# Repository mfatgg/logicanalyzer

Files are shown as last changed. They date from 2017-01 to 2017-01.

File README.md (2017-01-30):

# logicanalyzer

Hardware features:
- This is a DIY hobby project to build a simple logic analyzer.
- Firmware is done in C for an Atmel AVR Atmega32 controller.
- Cheap cache sram circuits from old 386 mainboards are used for fast sample snapshot storage.
- Prototype was build from scratch using wire wrap board with through-hole components.

Firmware features:
- Samplerate can be selected by user (divided from external crystal oscillator or manually switched).
- Pre-trigger and post-trigger length can be selected.
- Simple trigger conditions can be used.
- UART transport protection by CRC-16

Control software features:
- Serial communication library
- Set trigger and samplerate
- Get full snapshot ram content
- Verify correct serial transport by CRC-16
- Store logic analyter data in .VCD file for later viewing by e.g. GTKwave

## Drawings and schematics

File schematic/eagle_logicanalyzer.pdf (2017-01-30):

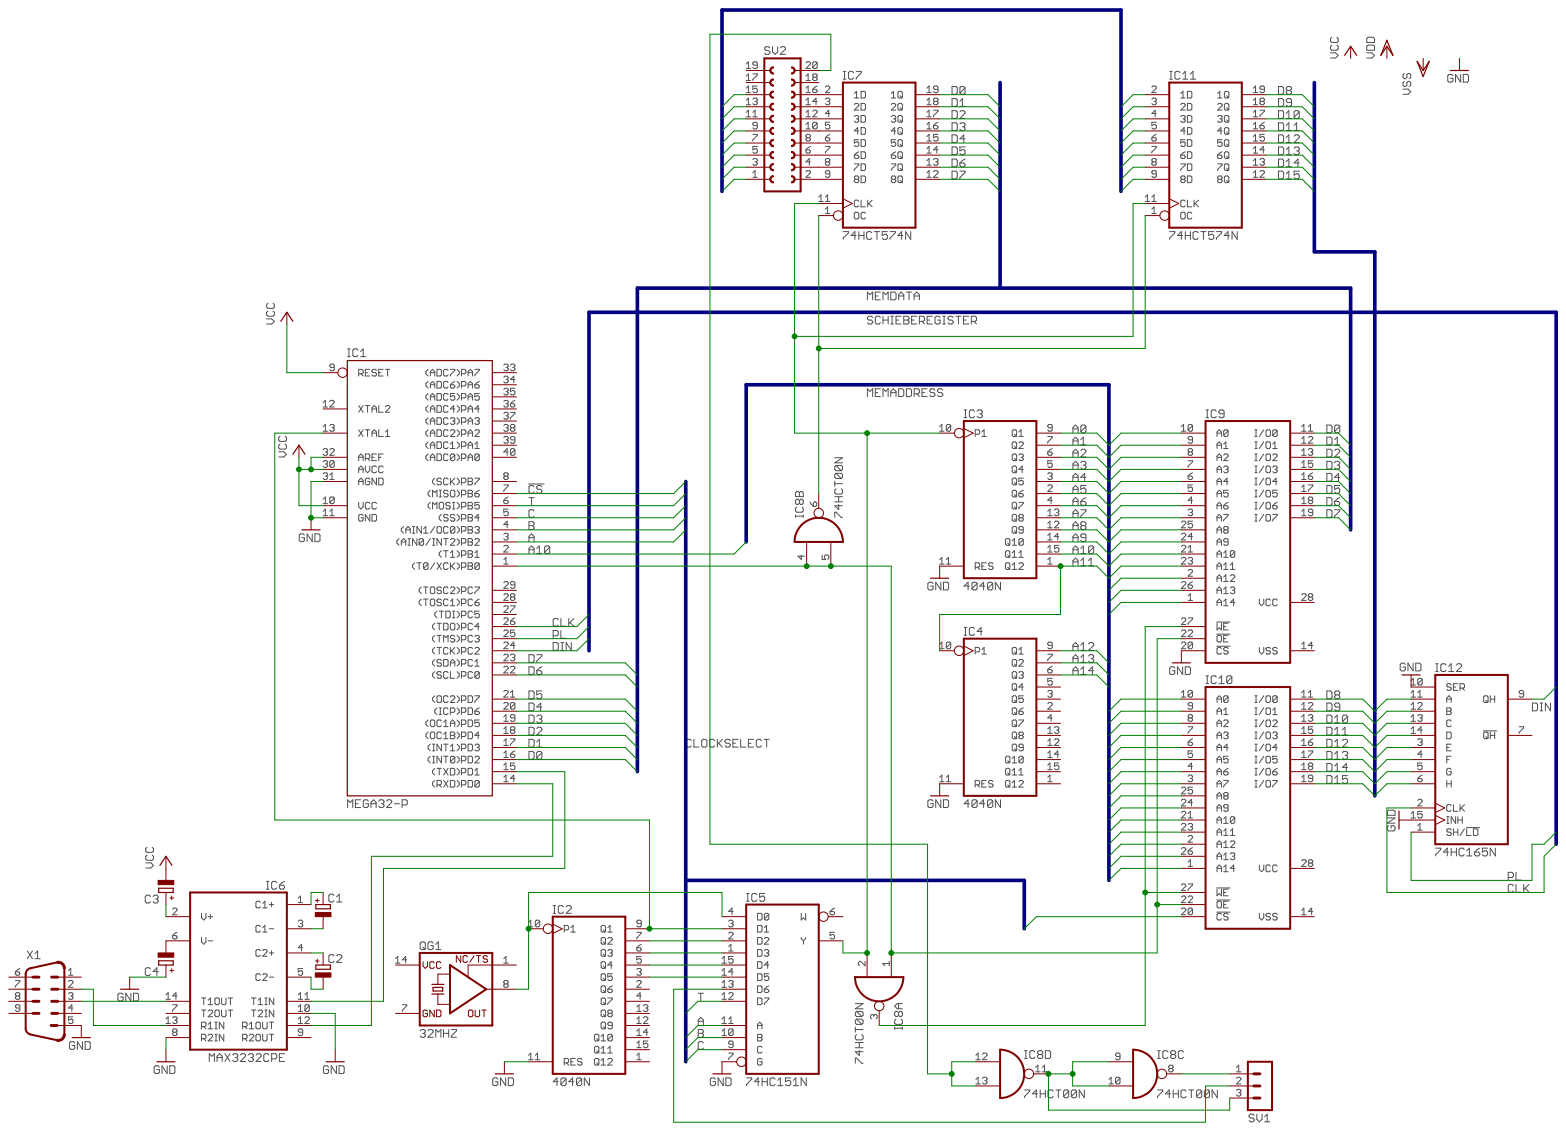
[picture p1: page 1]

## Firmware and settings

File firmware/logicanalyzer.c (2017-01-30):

#ifndef F_CPU
#warning "F_CPU was not defined before, will do now with 16000000"
#define F_CPU 16000000L    // system clock in Hz, "L" at the end is important, DO NOT use "UL"!
#endif

// Select soft uart for arbitrary avr pin usage
// (hardware uart is only available at dedicated pin locations)
#define USE_SOFTUART

//#define BAUD 500000L
//#define BAUD 460800L
//#define BAUD 230400L
#define BAUD 115200L
//#define BAUD 57600L
//#define BAUD 38400L
//#define BAUD 19200L

// Select size of sram circuit used [in bytes]
#define SRAMSIZE 32768L

// System includes
#include <avr/io.h>
#include <util/delay.h>
#include <avr/interrupt.h>

// User includes
#include "crc16.h"


#ifdef USE_SOFTUART

    /* Define external uart functions
     * (external source is assembly for critical uart timing to match baudrate)
    */
    #include "uart.h"
    // Obsolete hardware init for soft uart
    #define init_uart() ;

#else

    // Calculations
    #define UBRR_VAL ((F_CPU+BAUD*8)/(BAUD*16)-1)       // round cleverly
    #define BAUD_REAL (F_CPU/(16*(UBRR_VAL+1)))         // real baudrate
    #define BAUD_ERROR ((BAUD_REAL*1000)/BAUD-1000)     // error per mill

    // Verify selected baudrate can be used with minimal error for the given CPU clock.
    #if ((BAUD_ERROR>10) || (BAUD_ERROR<-10))
    #error Systematic baudrate error is too high! (> 1%)
    #endif

    /*
     * initialize the avr
     */
    void init_uart(void){
        UCSRB |= (1<<RXEN)|(1<<TXEN);                   // enable uart rx+tx
        UCSRC |= (1<<URSEL)|(1<<UCSZ1)|(1<<UCSZ0);      // async 8N1

        UBRRH = UBRR_VAL >> 8;
        UBRRL = UBRR_VAL & 0xFF;
    }

    // status register of newer AVRs have different names, here for ATmega16:
    void uart_putc(unsigned char c)
    {
        while (!(UCSRA & (1 << UDRE)));     // wait until sending is possible
        UDR = c;                            // send character
    }

    /*
     * receive a char over UART
     */
    uint8_t uart_getc( void )
    {
        /* Wait for data to be received */
        while (!(UCSRA & (1 << RXC)));
        /* Get and return received data from buffer */
        return UDR;
    }

#endif


/*
 * start counting write cycles:
 * enable extern T1 pin, falling edge
 */
#define starttimer() TCCR1B = ((1 << WGM12) | (3 << CS11))

/*
 * stop counting write cycles
 */
#define stoptimer() TCCR1B = (1 << WGM12)

/* switch SRAM to WRITE mode */
#define sramwritemode() PORTB |= 1

/* switch SRAM to READ mode */
#define sramreadmode() PORTB &= ~1

/* set SRAM clock line (T) to HIGH */
#define clkhigh() PORTB |= (1 << 5)

/* set SRAM clock line (T) to LOW */
#define clklow() PORTB &= ~(1 << 5)

/* write 1 byte (8 bit) to external SRAM */
#define sramwrite (data) \
    PORTD = (PORTD & ~(0xFC)) | ((data & 0x3F) << 2); \
    PORTC = (PORTC & ~(0x03)) | ((data & 0xC0) >> 6);

/* read 1 byte (8 bit) from external SRAM */
#define sramread() ((PIND & 0xFC) >> 2) | ((PINC & 0x03) << 6)

/*
 * select samplerate for next snapshot:
 *
 * 0 -> 32.00Mhz  (24.00 Mhz)
 * 1 -> 16.00Mhz  (12.00 Mhz)
 * 2 ->  8.00Mhz  ( 6.00 Mhz)
 * 3 ->  4.00MHz  ( 3.00 Mhz)
 * 4 ->  2.00MHz  ( 1.50 Mhz)
 * 5 ->  1.00MHz  ( 0.75 Mhz)
 * 6 -> external
 * 7 -> avr (internal)
 */
#define setsamplerate(srate) PORTB = (PORTB & ~(0x07 << 2)) | ((srate & 0x07) << 2)



// recording state (1 = on, 0 = off),
// volatile because it's used in interrupt routine
volatile uint8_t recording = 0;



void dataoutmode(void)
{
    /* PORT D:
        Bit0: UART-RX, Bit1: UART-TX, Bit2-7: D0-D5 */
    DDRD = 0xFE;
    PORTD = 0xFD;
    /* PORT C:
        Bit0-1: D6-D7 */
    DDRC = 0xFF;
    PORTC = 0xFF;
}


void datainmode(void)
{
    /* PORT D:
        Bit0: UART-RX, Bit1: UART-TX, Bit2-7: D0-D5 */
    DDRD = 0x02;
    PORTD = 0xFD;
    /* PORT C:
        Bit0-1: D6-D7 */
    DDRC = 0xFC;
    PORTC = 0xFF;
}


void init (void)
{
    DDRA = 0xFF;
    PORTA = 0xFF;
    DDRB = 0xFD;
    PORTB = 0x3C;
}


/*
 * set the counter
 */
void init_count(void){
    TCCR1A = 0;
    TCCR1B = (1 << WGM12);
    TCNT1 = 0;
    OCR1A = 15;     // count 15 falling edges of A10 line (=32k memory, 17k pretrigger?)
    TIMSK |= (1 << OCIE1A);
}


/*
 * Long variable delay time, unit in ms.
 *
 * Maximum time per function call is limitted to 262.14 ms / F_CPU in MHz.
 *
 * For this the waiting loop function is called several times to get longer delays.
 * The additional checking of the loop condition gives a little inaccuracy in
 * delay time (about 2 to 3 ms).
 *
*/
void long_delay(uint16_t ms) {
    for(; ms>0; ms--) _delay_ms(1);
}



/*
 * main loop
 */
int main(void)
{
    uint8_t trig, samp, c;
    uint8_t i;
    uint16_t j;

    // Initialize system (start condition)
    init();
    datainmode();
    init_uart();

    _delay_ms(1);

    sei();

    while(1) {

        // Wait for start of communication by control software,
        // character 'L' means start.
        while (uart_getc() != 'L') {};
        trig = uart_getc();  //2nd character received = trigger selection
        samp = uart_getc();  //3rd character received = samplerate selection

        // Init acquisition state machine
        setsamplerate(samp);
        init_count();
        sramwritemode();
        // Start sample snapshot recording
        recording = 1;
        // Wait until SRAM is written completely at least 1 time.
        // Max. duration: 32ms for 1MHz = 32000 Bytes written.
        long_delay(40);

        // Process trigger selection: rising, falling, no
        switch(trig) {
            case 'r':
                // INT0 clear
                GIFR = 0x40;
                // INT0 rising edge trigger
                MCUCR = (MCUCR & 0xF0) | 0x03;
                // INT0 enable
                GICR |= (1 << INT0);
                break;
            case 'f':
                // INT0 clear
                GIFR = 0x40;
                // INT0 falling edge trigger
                MCUCR = (MCUCR & 0xF0) | 0x02;
                // INT0 enable
                GICR |= (1 << INT0);
                break;
            default:
                // no trigger = immediately run snapshot timer
                starttimer();
        }

        // wait until snapshot recording is done
        while(recording){}

        // output to PC and calculate CRC16 for transport protection
        uart_putc('K');
        // transmit single blocks with blocksize = 8192
        // 8192 = max. size to detect single bit errors
        for(i = 0; i < (SRAMSIZE / 8192); i++){
            // crc init value
            crc16 = 0xffff;;
            for (j = 0; j < 8192; j++){
                clkhigh();
                clklow(); // clock next value
                c = sramread();
                calc_crc16(c);
                uart_putc(c);
            }
            // transmit crc16 after each block as 2 characters
            uart_putc(crc16 & 0xff);
            uart_putc(crc16 >> 8);
        }
    }

    return 0;
}

/*
 * Gets called when "snapshot done" condition occurs (=watch SRAM fill level) -> stop recording.
 * (Timer ISR gets called after A10 memory address line was triggered selected number of times.
 *  By changing OCR1A register value (=number of A10 triggers counted)
 *  -> pre-trigger and post-trigger length can be selected.)
 */
ISR(TIMER1_COMPA_vect)
{
    setsamplerate(7);   // select manual avr sample clock (stop sampling)
    sramreadmode();     // switch SRAM to read mode
    stoptimer();        // stop timer
    recording = 0;      // stop snapshot recording
}

/*
 * Trigger condition found
 * -> disable INT0 (no re-trigger allowed)
 * -> start counting SRAM fill level (stop when full)
 */
ISR(INT0_vect)
{
    GICR &= ~(1 << INT0);
    starttimer();
}

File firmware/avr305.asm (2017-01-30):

;**** A P P L I C A T I O N   N O T E   A V R 3 0 5 ************************
;*
;* Title		: Half Duplex Interrupt Driven Software UART
;* Version		: rev. 1.2 (24-04-2002), reset vector added
;*			: rev. 1.1 (27.08.1997)
;* Last updated		: 24-04-2002
;* Target		: AT90S1200 
;*			  Can be used with all AVR Device. In devices without HW
;*			  stack the stackpointer must be set up.
;*
;* Support email	: avr@atmel.com
;*
;* Code Size		: 32 Words
;* Low Register Usage	: 0
;* High Register Usage	: 4
;* Interrupt Usage	: None
;*
;* DESCRIPTION
;* This Application note contains a very code efficient software UART.
;* The example program receives one character and echoes it back.
;***************************************************************************

.include "1200def.inc"

;***** Pin definitions

.equ	RxD	=0			;Receive pin is PD0
.equ	TxD	=1			;Transmit pin is PD1

;***** Global register variables

.def	bitcnt	=R16			;bit counter
.def	temp	=R17			;temporary storage register

.def	Txbyte	=R18			;Data to be transmitted
.def	RXbyte	=R19			;Received data

.cseg
.org 0
	rjmp	reset
;***************************************************************************
;*
;* "putchar"
;*
;* This subroutine transmits the byte stored in the "Txbyte" register
;* The number of stop bits used is set with the sb constant
;*
;* Number of words	:14 including return
;* Number of cycles	:Depens on bit rate
;* Low registers used	:None
;* High registers used	:2 (bitcnt,Txbyte)
;* Pointers used	:None
;*
;***************************************************************************
.equ		sb	=1		;Number of stop bits (1, 2, ...)

putchar:	ldi	bitcnt,9+sb	;1+8+sb (sb is # of stop bits)
		com	Txbyte		;Inverte everything
		sec			;Start bit

putchar0:	brcc	putchar1	;If carry set
		cbi	PORTD,TxD	;    send a '0'
		rjmp	putchar2	;else	

putchar1:	sbi	PORTD,TxD	;    send a '1'
		nop

putchar2:	rcall UART_delay	;One bit delay
		rcall UART_delay

		lsr	Txbyte		;Get next bit
		dec	bitcnt		;If not all bit sent
		brne	putchar0	;   send next
					;else
		ret			;   return


;***************************************************************************
;*
;* "getchar"
;*
;* This subroutine receives one byte and returns it in the "Rxbyte" register
;*
;* Number of words	:14 including return
;* Number of cycles	:Depens on when data arrives
;* Low registers used	:None
;* High registers used	:2 (bitcnt,Rxbyte)
;* Pointers used	:None
;*
;***************************************************************************

getchar:	ldi 	bitcnt,9	;8 data bit + 1 stop bit

getchar1:	sbic 	PIND,RxD	;Wait for start bit
		rjmp 	getchar1

		rcall UART_delay	;0.5 bit delay

getchar2:	rcall UART_delay	;1 bit delay
		rcall UART_delay		

		clc			;clear carry
		sbic 	PIND,RxD	;if RX pin high
		sec			;

		dec 	bitcnt		;If bit is stop bit
		breq 	getchar3	;   return
					;else
		ror 	Rxbyte		;   shift bit into Rxbyte
		rjmp 	getchar2	;   go get next

getchar3:	ret


;***************************************************************************
;*
;* "UART_delay"
;*
;* This delay subroutine generates the required delay between the bits when
;* transmitting and receiving bytes. The total execution time is set by the
;* constant "b":
;*
;*	3·b + 7 cycles (including rcall and ret)
;*
;* Number of words	:4 including return
;* Low registers used	:None
;* High registers used	:1 (temp)
;* Pointers used	:None
;*
;***************************************************************************
; Some b values: 	(See also table in Appnote documentation)
;
; 1 MHz crystal:
;   9600 bps - b=14
;  19200 bps - b=5
;  28800 bps - b=2
;
; 2 MHz crystal:
;  19200 bps - b=14
;  28800 bps - b=8
;  57600 bps - b=2

; 4 MHz crystal:
;  19200 bps - b=31
;  28800 bps - b=19
;  57600 bps - b=8
; 115200 bps - b=2

.equ	b	=31	;19200 bps @ 4 MHz crystal


UART_delay:	ldi	temp,b
UART_delay1:	dec	temp
		brne	UART_delay1

		ret

;***** Program Execution Starts Here

;***** Test program

reset:		sbi	PORTD,TxD	;Init port pins
		sbi	DDRD,TxD

		ldi	Txbyte,12	;Clear terminal
		rcall	putchar

forever:	rcall	getchar
		mov	Txbyte,Rxbyte
		rcall	putchar		;Echo received char
		rjmp	forever
